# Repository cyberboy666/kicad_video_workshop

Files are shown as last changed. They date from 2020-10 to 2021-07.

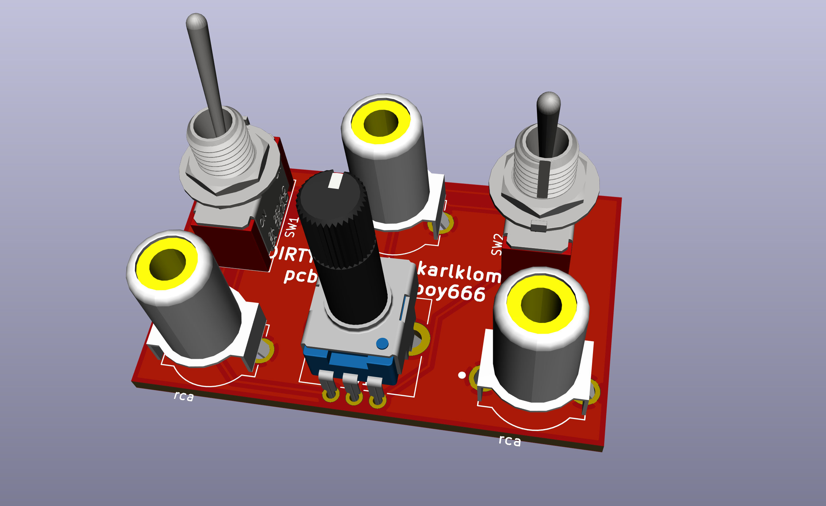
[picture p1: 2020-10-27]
demo_project_complete/demo_render.png

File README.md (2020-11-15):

# kicad_video_workshop

an interactive kicad workshop for diy video-art making instruments

## getting started:

- download [kicad](https://kicad-pcb.org/download/) ( version >=5 )
- download _this_ repo (git clone or as zip under _code_ here)
- open the file in _workshop_project_ / __workshop_project.pro__ with kicad

## the challenge:

together we will try to adapt a video glitch processing circuit created orginally by [Karl Klomp](https://www.karlklomp.nl/) known as __the rupter__. this project and many other interesting historic video hardware glitch machines can be seen on [web-archive](https://web.archive.org/web/20150206171254/https://www.karlklomp.nl/) of their site.

<details>
<summary>details of the original circuit</summary>

### original circuit:

(https://vimeo.com/13738566)









### my interpretation:

- [video demo](https://videos.scanlines.xyz/videos/watch/c60b0d9a-0be3-4889-8f0d-863ae294ad4a)

there are a few quirks of this design that make it difficult to adapt to a pcb project:

- its not clear which pot values to use - 100k or 1k ? (100ohm pots are bery uncommon) after testing i liked the effects with 1k_pots better
- although possible to use a rotary switch on pcb, the footprints for these are a little complicated and i opted to use some (cheap) slide switches in parallel instead. lower resistor values seemed to work better here than higher ones. you should experiment for yourself which values to use here !
- a 'circuit bent' style schematic can be difficult to understand since often are based on misusing components. Bastien made a [simulation](https://tinyurl.com/yyvfhpfx) of the first stage which doesnt appear to do much in theory. as is often the case things will be different in practice. 

### further notes on the circuit

from building:

- tried skipping the power regulator part and going 5v straight into the ic -> seems to work quite well 
- [lm317](http://www.learningaboutelectronics.com/Articles/LM317-voltage-regulator) is adjustable voltage regulator - ouput voltage is `1.25*(1 + r2/r1)` where in this case r2=1k and r1=220ohm. so voltage output should be around 7v. confirmed this when building
- i measured the current from the lm317 and was around 20mA so could also use the smaller/cheaper [part](https://www.taydaelectronics.com/lm317lz-lm317l-lm317-0-1a-voltage-regulator-ic.html)
- tried with 200ohm , 1k and 100k pots. all were quite interesting. i would choose 1k pots myself.
- tried with some different cap values. no cap connected gives closer to a clean signal. higher caps tend to just give dropouts (with a few hard to tune effects) lower values seems most interesting. i would experiment some more with which cap values to use.
- i tried to figure out which way to orieintate the pots to make most sense. still it is not that obvious to me. would have to play around with the circuit some more to fine tune this.
- i tried switching -in/out of second opamp to see if liked the effect better but it wasnt as interesting.
- i tested with ntsc and it seems to give better colour glitches than as i remember with pal

</details>

## the schematic

here is a handdrawn schematic of my interpretation which we will try to create in kicad:



## some kicad shortcuts

Schematics shortcuts:

- __a__ to add symbol
- __m__ to move symbol
- __e__ to edit symbol
- __c__ to duplicate symbol
- __w__ to draw wire
- _esc_ to return to pointer tool

pcb_route shortcuts:

- __m__ to move item
- __x__ to route track
- __v__ to add via
- _esc_ to return to pointer tool

## links to parts used:

part | footprint | link
--- | --- | ---
rca_jack | - | [mouser](https://www.mouser.de/ProductDetail/CUI-Devices/RCJ-024?qs=%2Fha2pyFaduhcVxkiXFV6ZkU5qdMo9ssjy3LnObhig%2FI%3D), [ali](https://www.aliexpress.com/item/32851836707.html)
spdt_slide_switch | - | [tayda](https://www.taydaelectronics.com/slide-switch-1p2t-through-hole-0-3a-30vdc.html)
spdt_toggle_switch | - | [tayda](https://www.taydaelectronics.com/mini-toggle-switch-spdt-on-none-on.html)
dpst_slide_switch | - | [tayda](https://www.taydaelectronics.com/slide-switch-dpdt-solder-lug-3a-250vac.html)
dpst_toggle_switch | - | [tayda](https://www.taydaelectronics.com/mini-toggle-switch-dpdt-on-on.html)
ad8072 | - | [mouser_dip](https://www.mouser.de/ProductDetail/Analog-Devices/AD8072JNZ?qs=%2FtpEQrCGXCyHkd%2F8k%2FoSBQ%3D%3D)
1k_pot | - | [tayda](https://www.taydaelectronics.com/1k-ohm-linear-taper-potentiometer-round-knurled-plastic-shaft-pcb-9mm.html), [mouser](https://www.mouser.de/ProductDetail/Bourns/PTV09A-4225F-B102?qs=Qzws7J6gxqyeFhc0kO3Q7A%3D%3D)
7pst_rotary_switch | none | [tayda](https://www.taydaelectronics.com/rotary-switch-1-pole-7-position-alpha-sr2511-3599.html), [mouser](https://www.mouser.de/ProductDetail/Alpha-Taiwan/SR2511F-0107-19R0B-E9-S-W-159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)

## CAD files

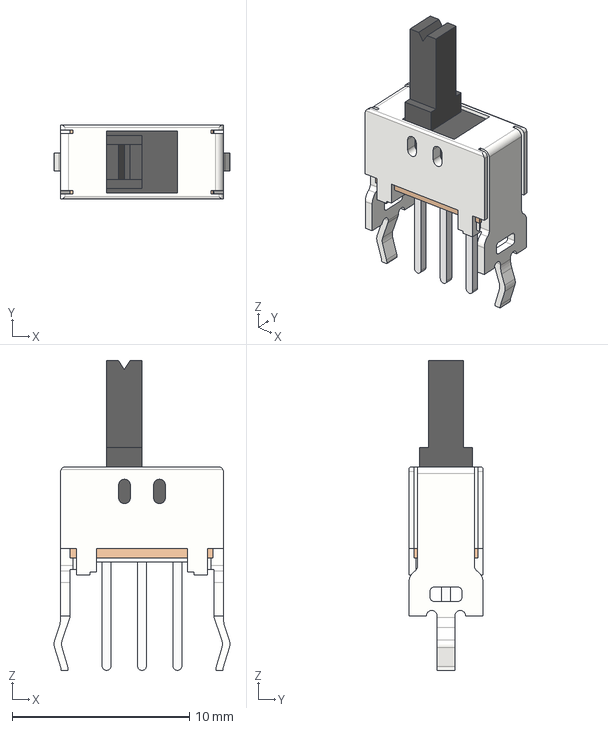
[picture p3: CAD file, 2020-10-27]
demo_project_complete/3dmodels/spdt_slide_switch.step
9.93 x 4.20 x 17.5 mm

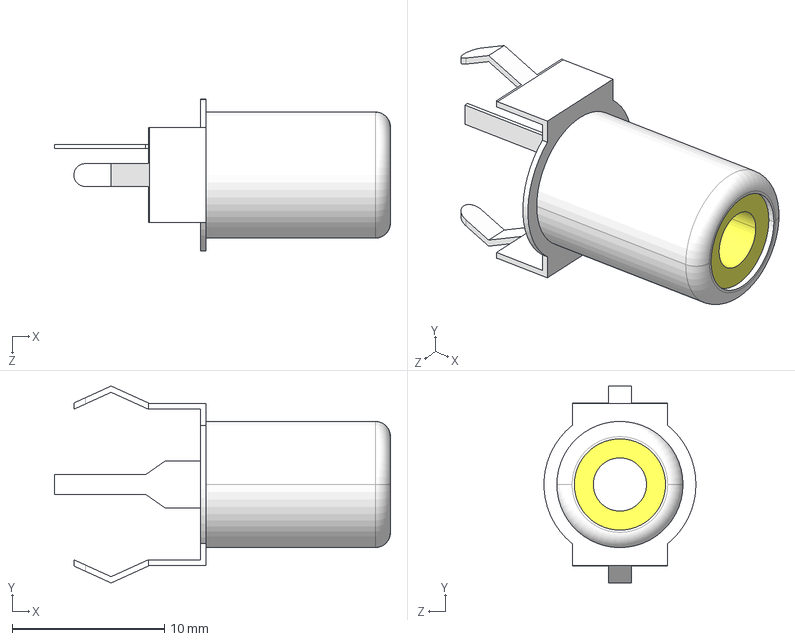
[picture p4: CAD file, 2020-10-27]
demo_project_complete/3dmodels/rca_vertical.step
22.1 x 13.0 x 9.99 mm

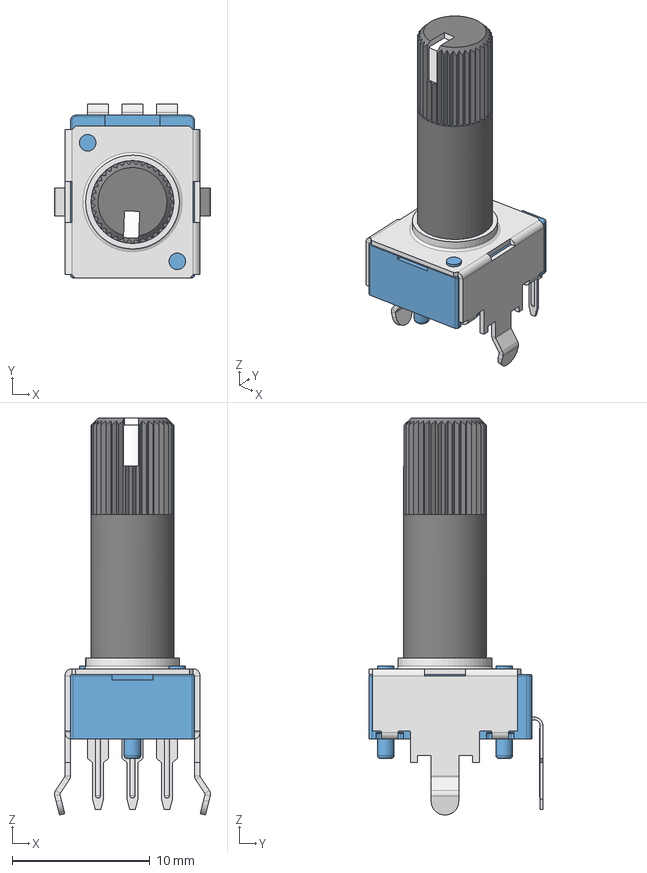
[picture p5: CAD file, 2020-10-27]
demo_project_complete/3dmodels/pot_vertical.step
11.3 x 12.6 x 28.8 mm

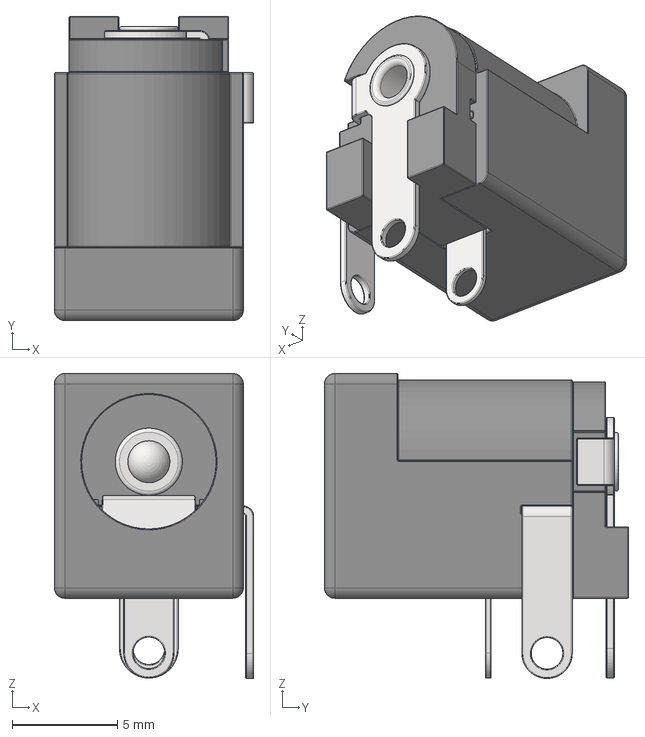
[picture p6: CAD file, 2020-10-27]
workshop_project_complete/3dmodels/barrel_jack.stp
9.49 x 14.5 x 14.5 mm

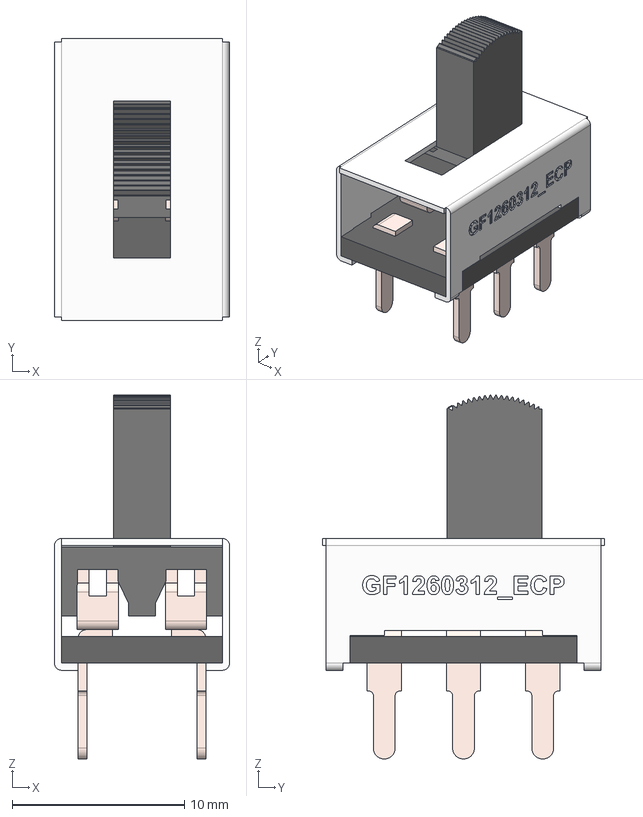
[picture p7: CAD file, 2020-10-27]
demo_project_complete/3dmodels/dpdt_slide_switch.step
10.2 x 16.4 x 21.1 mm
pcb
knob

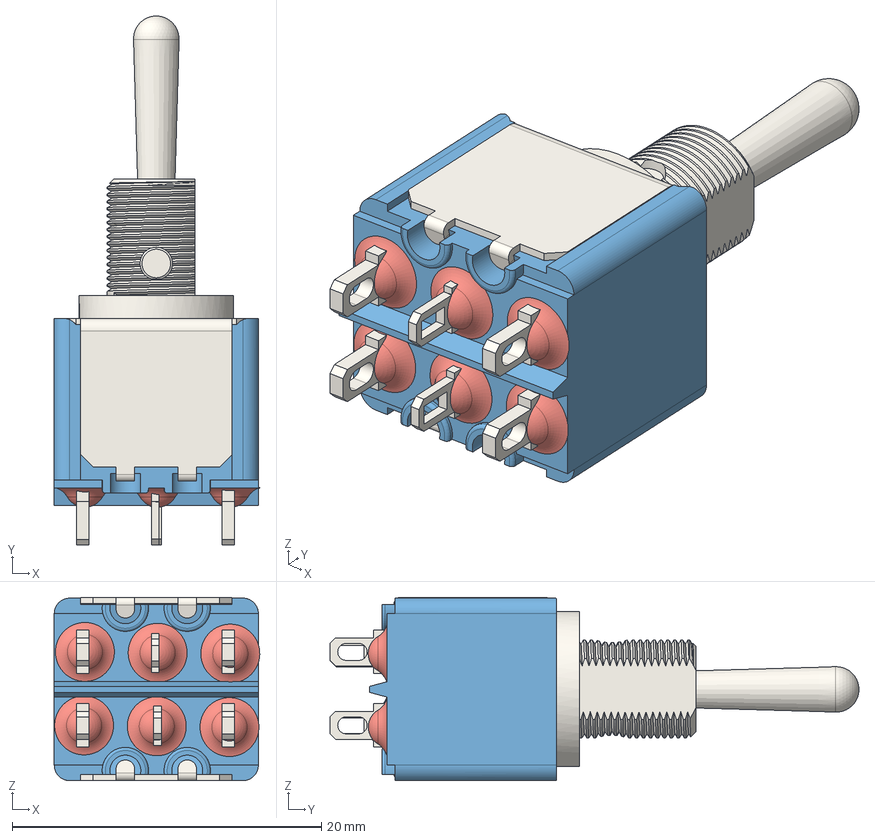
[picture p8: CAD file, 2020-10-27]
demo_project_complete/3dmodels/dpdt_toggle_switch.step
13.3 x 34.2 x 11.9 mm

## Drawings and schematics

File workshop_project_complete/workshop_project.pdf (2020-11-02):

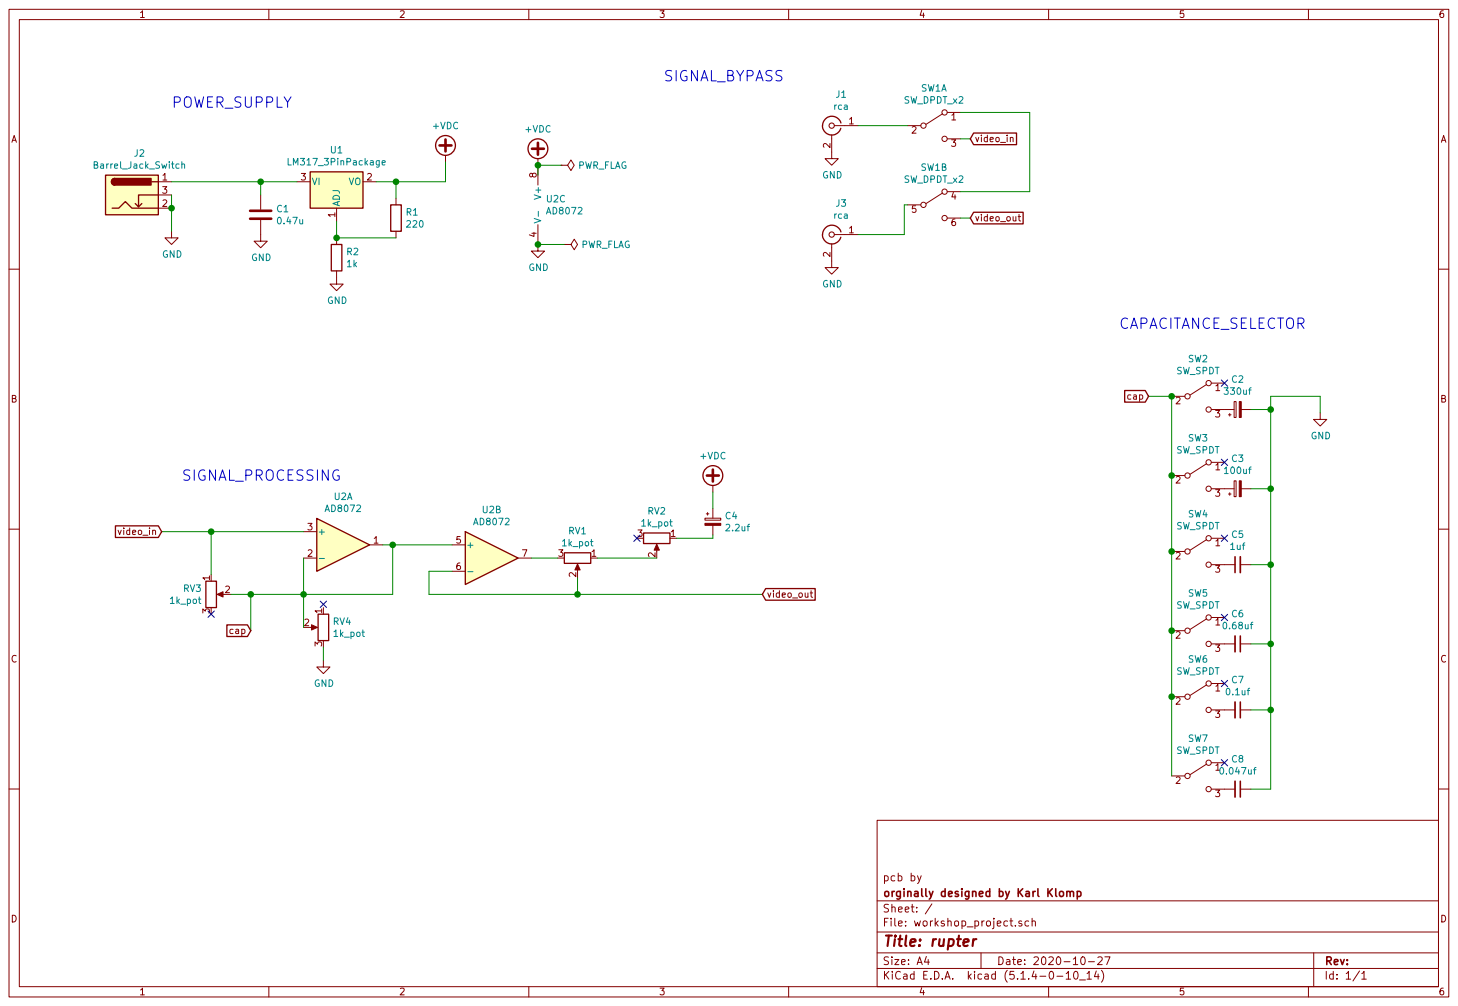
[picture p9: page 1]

pcb by
File: workshop_project.sch Sheet: / orginally designed by Karl Klomp

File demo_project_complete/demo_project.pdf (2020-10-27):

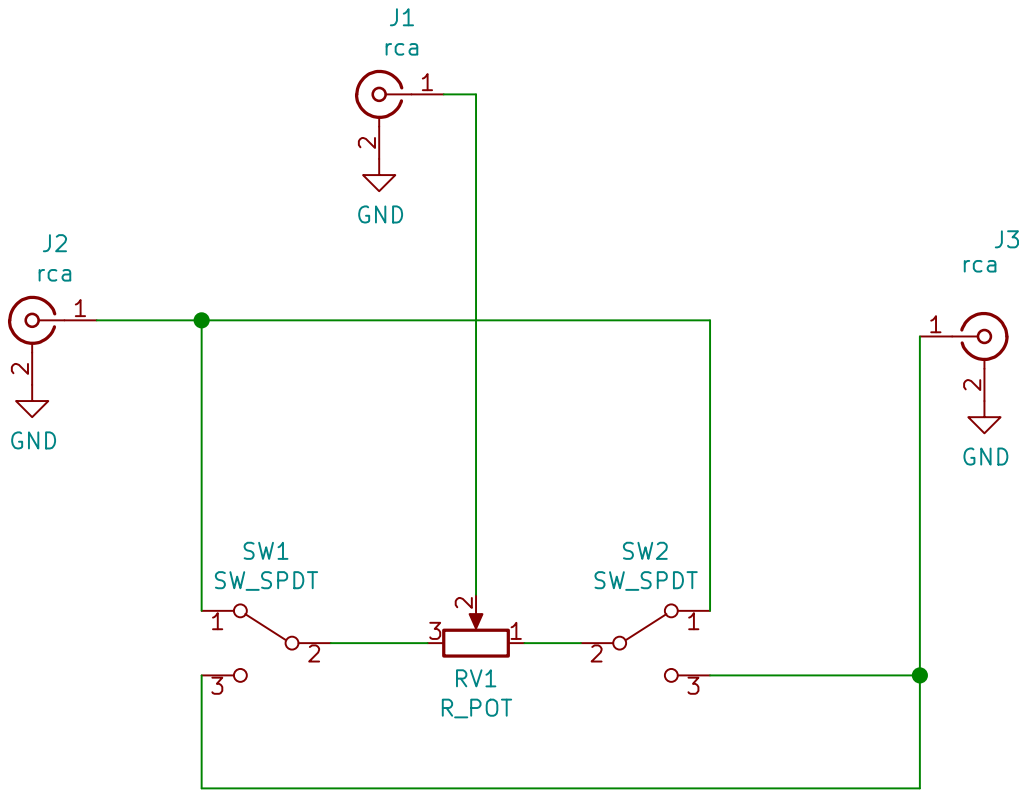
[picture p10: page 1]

File: demo_project.sch Sheet: / pcb by cyberboy666

Id: 1/1 Title: dirtymixer by karlklomp

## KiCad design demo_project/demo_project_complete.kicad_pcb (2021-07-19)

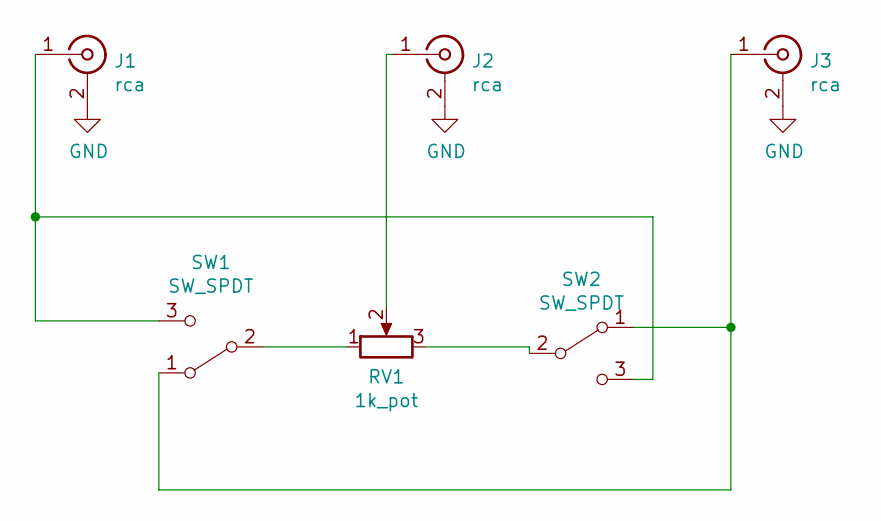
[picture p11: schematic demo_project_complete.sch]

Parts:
J1, J2, J3: rca; rca_vertical
RV1: 1k_pot; pot_vertical_9mm
SW1, SW2: SW_SPDT; spdt_slide_switch_small_tayda

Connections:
GND: J1.2 (Ext), J2.2 (Ext), J3.2 (Ext)
unnamed: J1.1 (In), SW1.3 (C), SW2.3 (C)
unnamed: J2.1 (In), RV1.2
unnamed: J3.1 (In), SW1.1 (A), SW2.1 (A)
unnamed: RV1.1, SW1.2 (B)
unnamed: RV1.3, SW2.2 (B)

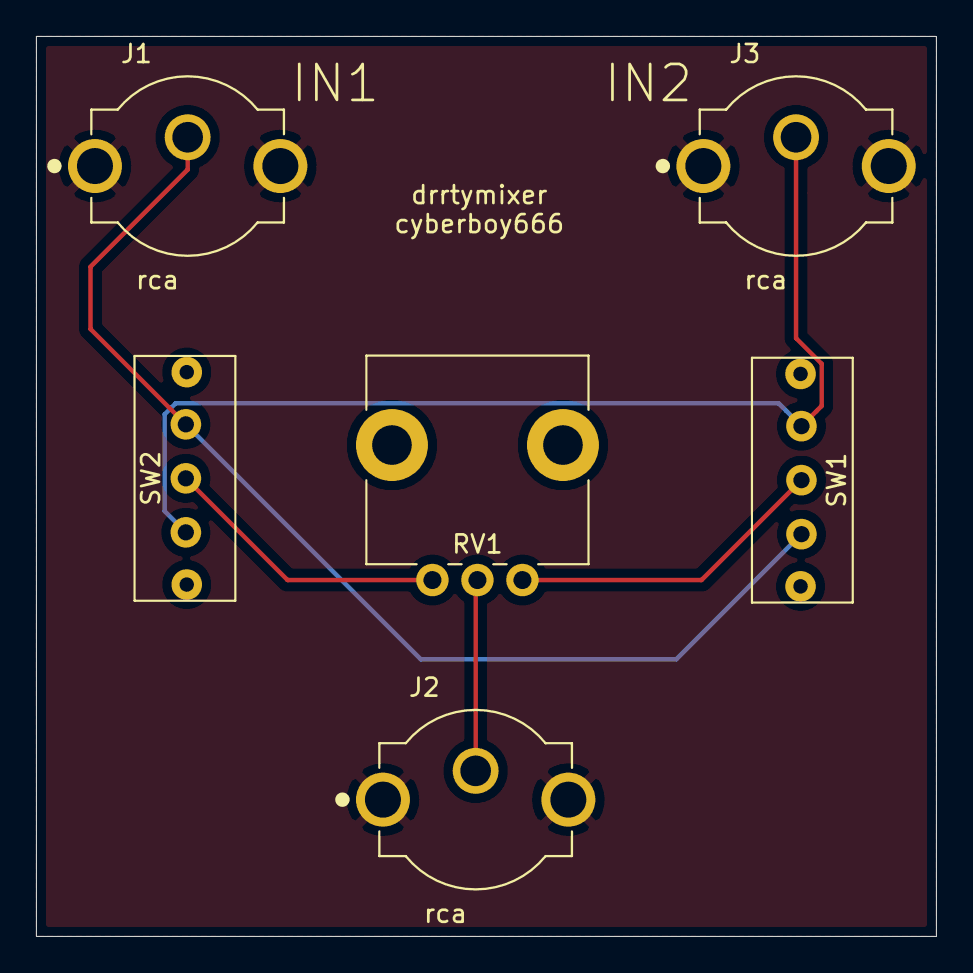
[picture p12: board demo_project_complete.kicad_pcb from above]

Board: 2 copper layers, 50.0 x 50.0 mm, 6 parts (0 on the bottom side), 6 nets.

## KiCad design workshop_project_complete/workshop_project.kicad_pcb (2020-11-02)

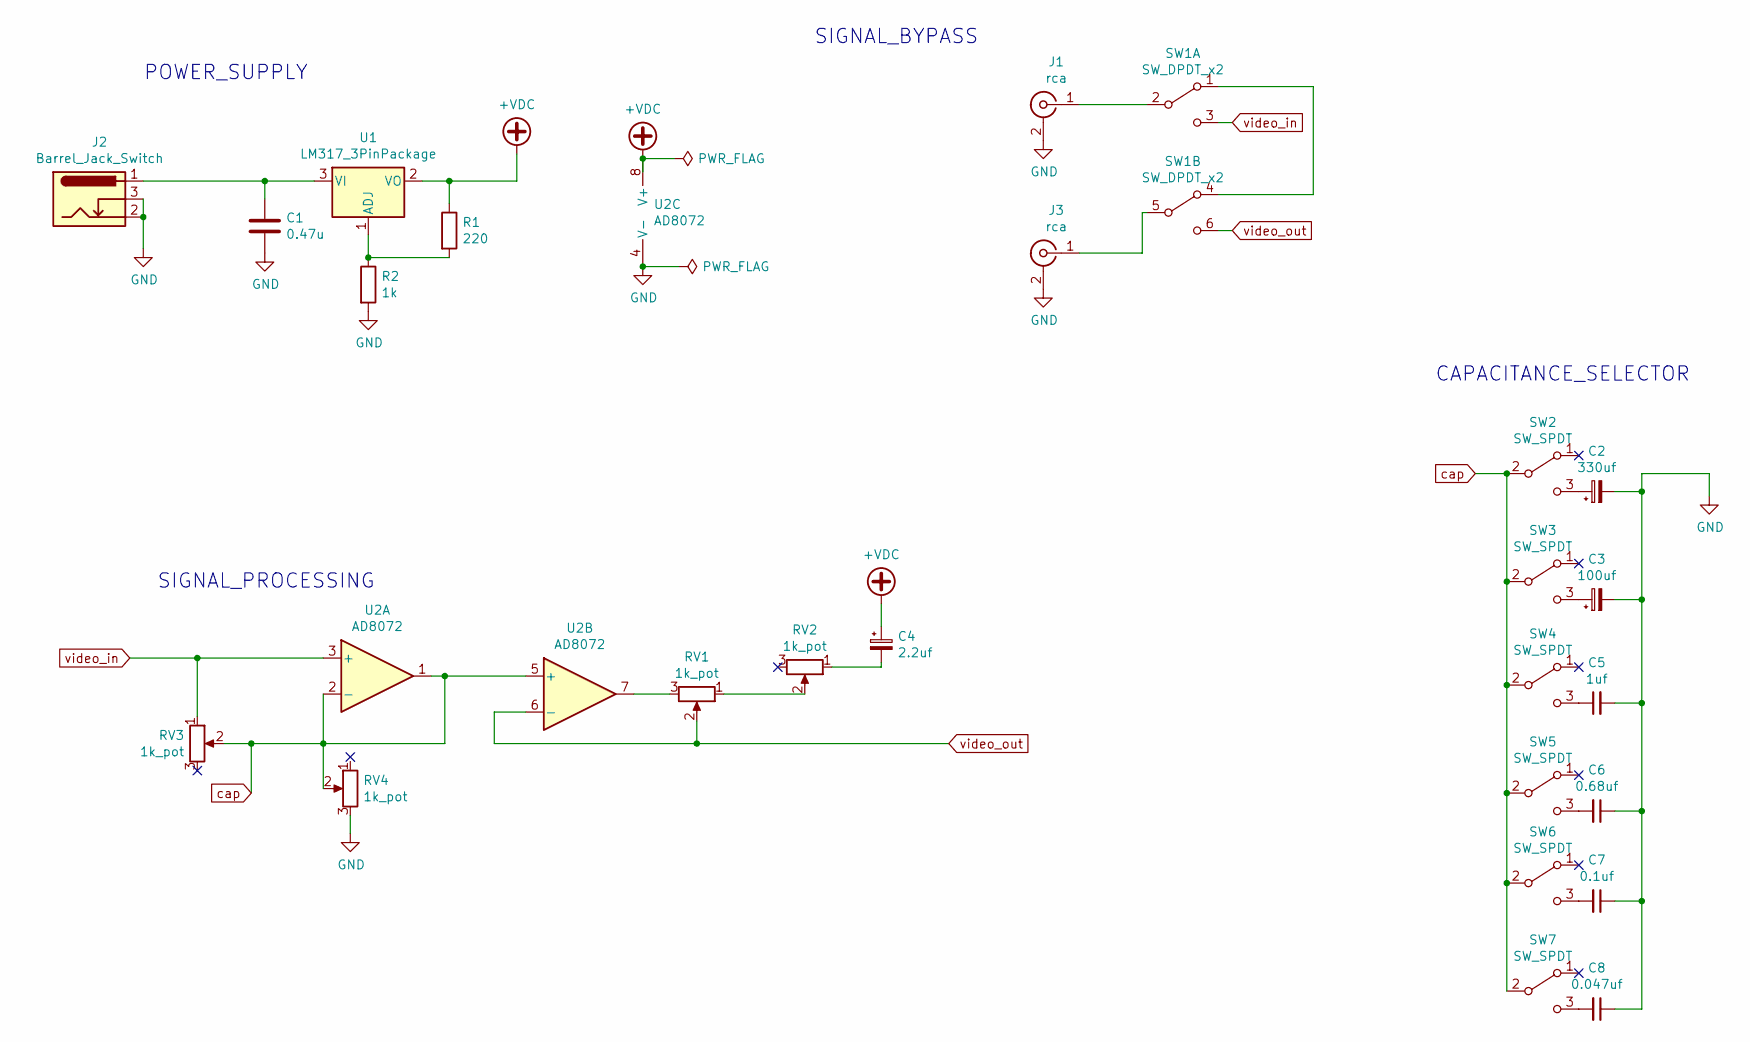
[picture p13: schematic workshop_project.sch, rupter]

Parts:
C1: 0.47u; CP_Radial_D5.0mm_P2.50mm
C2: 330uf; CP_Radial_D5.0mm_P2.50mm
C3: 100uf; CP_Radial_D5.0mm_P2.50mm
C4: 2.2uf; CP_Radial_D5.0mm_P2.50mm
C5: 1uf; C_Disc_D4.7mm_W2.5mm_P5.00mm
C6: 0.68uf; C_Disc_D4.7mm_W2.5mm_P5.00mm
C7: 0.1uf; C_Disc_D4.7mm_W2.5mm_P5.00mm
C8: 0.047uf; C_Disc_D4.7mm_W2.5mm_P5.00mm
J1, J3: rca; rca_vertical
J2: Barrel_Jack_Switch; BarrelJack_Horizontal
R1: 220; R_Axial_DIN0204_L3.6mm_D1.6mm_P5.08mm_Horizontal
R2: 1k; R_Axial_DIN0204_L3.6mm_D1.6mm_P5.08mm_Horizontal
RV1, RV2, RV3, RV4: 1k_pot; pot_vertical_9mm
SW1: SW_DPDT_x2; dpdt_mini_toggle_switch_tayda
SW2, SW3, SW4, SW5, SW6, SW7: SW_SPDT; spdt_slide_switch_small_tayda
U1: LM317_3PinPackage; TO-92L_HandSolder
U2: AD8072; DIP-8_W7.62mm_LongPads

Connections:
+VDC: C4.1, R1.1, U1.2 (VO), U2.8 (V+)
GND: C1.2, C2.2, C3.2, C5.2, C6.1, C7.1, C8.1, J1.2 (Ext), J2.2, J2.3, J3.2 (Ext), R2.2, RV4.3, U2.4 (V-)
unnamed: C1.1, J2.1, U1.3 (VI)
unnamed: C2.1, SW2.3 (C)
unnamed: C3.1, SW3.3 (C)
unnamed: C4.2, RV2.1
unnamed: C5.1, SW4.3 (C)
unnamed: C6.2, SW5.3 (C)
unnamed: C7.2, SW6.3 (C)
unnamed: C8.2, SW7.3 (C)
unnamed: J1.1 (In), SW1.2 (B)
unnamed: J3.1 (In), SW1.5 (B)
unnamed: R1.2, R2.1, U1.1 (ADJ)
unnamed: RV1.1, RV2.2
unnamed: RV1.3, U2.7
unnamed: SW1.1 (A), SW1.4 (A)
cap: RV3.2, RV4.2, SW2.2 (B), SW3.2 (B), SW4.2 (B), SW5.2 (B), SW6.2 (B), SW7.2 (B), U2.1, U2.2 (-), U2.5 (+)
video_in: RV3.1, SW1.3 (C), U2.3 (+)
video_out: RV1.2, SW1.6 (C), U2.6 (-)

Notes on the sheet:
POWER_SUPPLY
SIGNAL_PROCESSING
SIGNAL_BYPASS
CAPACITANCE_SELECTOR

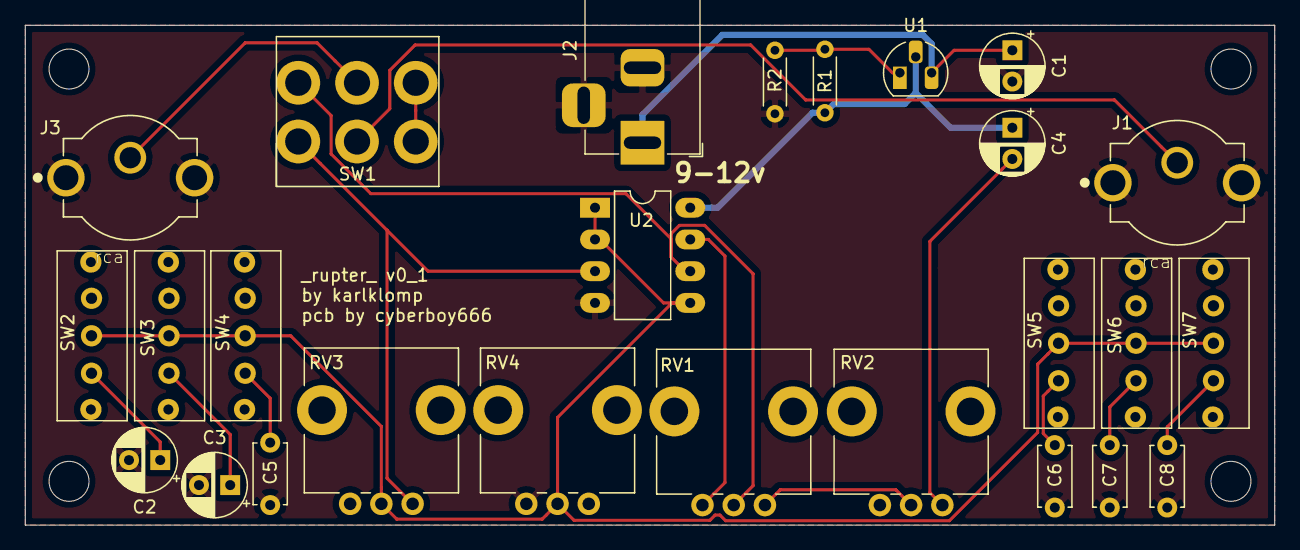
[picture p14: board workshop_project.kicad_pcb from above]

Board: 2 copper layers, 100.0 x 40.0 mm, 26 parts (0 on the bottom side), 19 nets.

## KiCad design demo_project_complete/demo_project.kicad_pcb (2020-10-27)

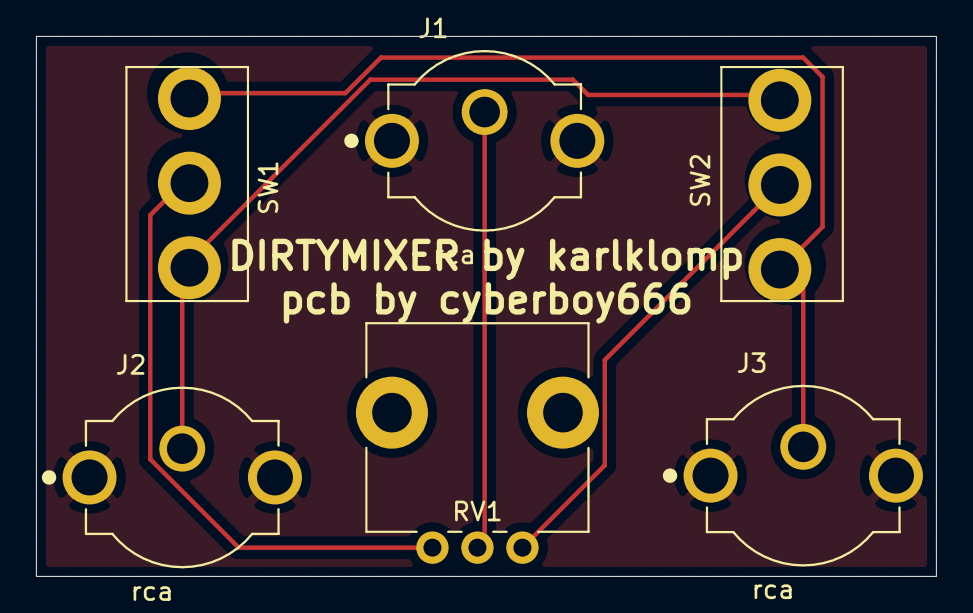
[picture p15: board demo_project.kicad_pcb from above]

Board: 2 copper layers, 50.0 x 30.0 mm, 6 parts (0 on the bottom side), 6 nets.

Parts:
J1, J2, J3: rca; rca_vertical
RV1: R_POT; pot_vertical_9mm
SW1, SW2: SW_SPDT; spdt_mini_toggle_switch_tayda

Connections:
GND: J1.2, J2.2, J3.2
unnamed: J1.1, RV1.2
unnamed: J2.1, SW1.1, SW2.1
unnamed: J3.1, SW1.3, SW2.3
unnamed: RV1.1, SW2.2
unnamed: RV1.3, SW1.2

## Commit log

2020-10-27 adding files for the workshop
    [barrel_jack.stp, demo_project.kicad_pcb, demo_project.sch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]
2020-10-28 added complete examples
    [barrel_jack.stp, demo_project.kicad_pcb, demo_project.sch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]
2020-11-02 update workshop complete
    [workshop_project.kicad_pcb, workshop_project.sch]
2021-07-19 small update
    [demo_project_complete.kicad_pcb, demo_project_complete.sch, workshop_project.sch]
